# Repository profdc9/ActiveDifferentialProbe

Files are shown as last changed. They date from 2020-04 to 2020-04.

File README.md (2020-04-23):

This is an Active RF Differential Probe based on a cheaply available 2SC3356 Bipolar Transistor by Daniel L. Marks, KW4TI.  Dual gate Mosfets are getting hard to find, so this is what I suggest as an alternative.

The bandwidth is approximately 1 GHz (-3 dB) with 6 dB gain at low frequency.

The PCB design is distributed under the Creative Commons Shared Alike Attribution (CC-BY-SA 4.0) license.

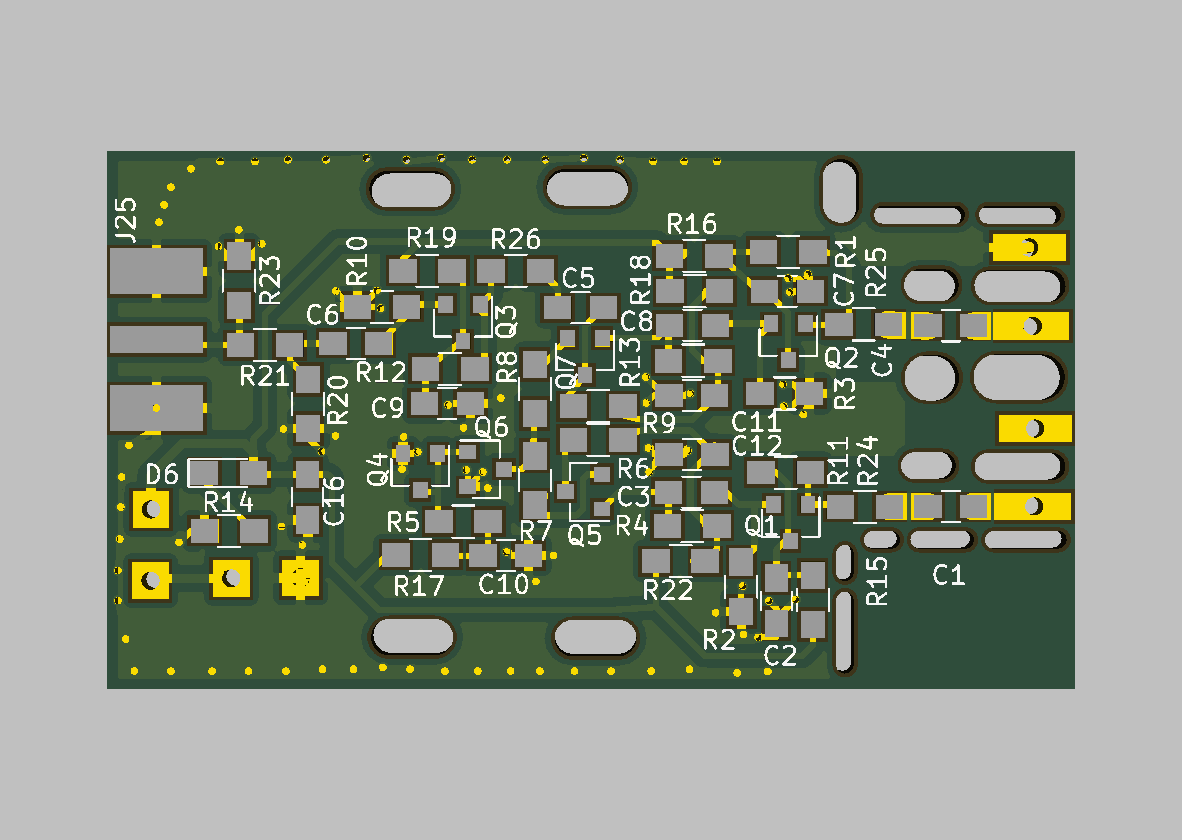
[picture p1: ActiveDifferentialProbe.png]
x


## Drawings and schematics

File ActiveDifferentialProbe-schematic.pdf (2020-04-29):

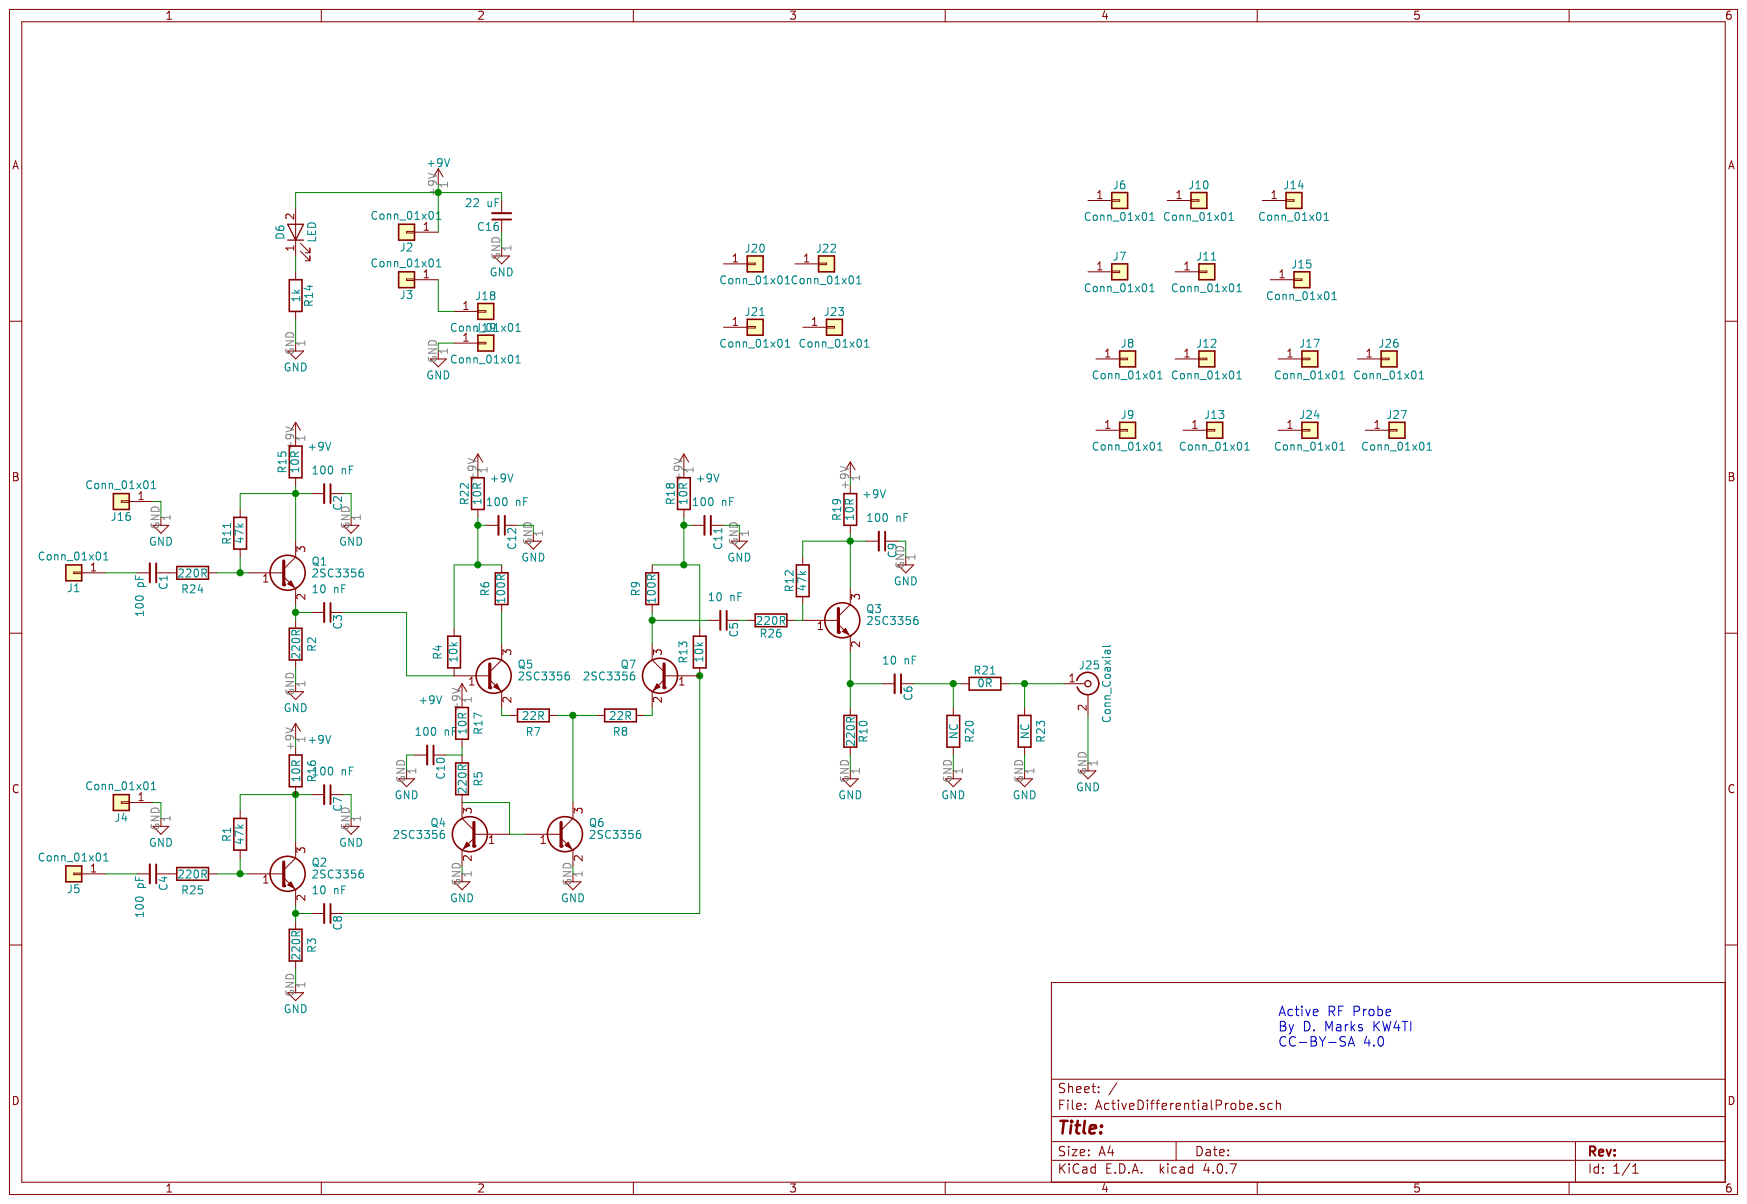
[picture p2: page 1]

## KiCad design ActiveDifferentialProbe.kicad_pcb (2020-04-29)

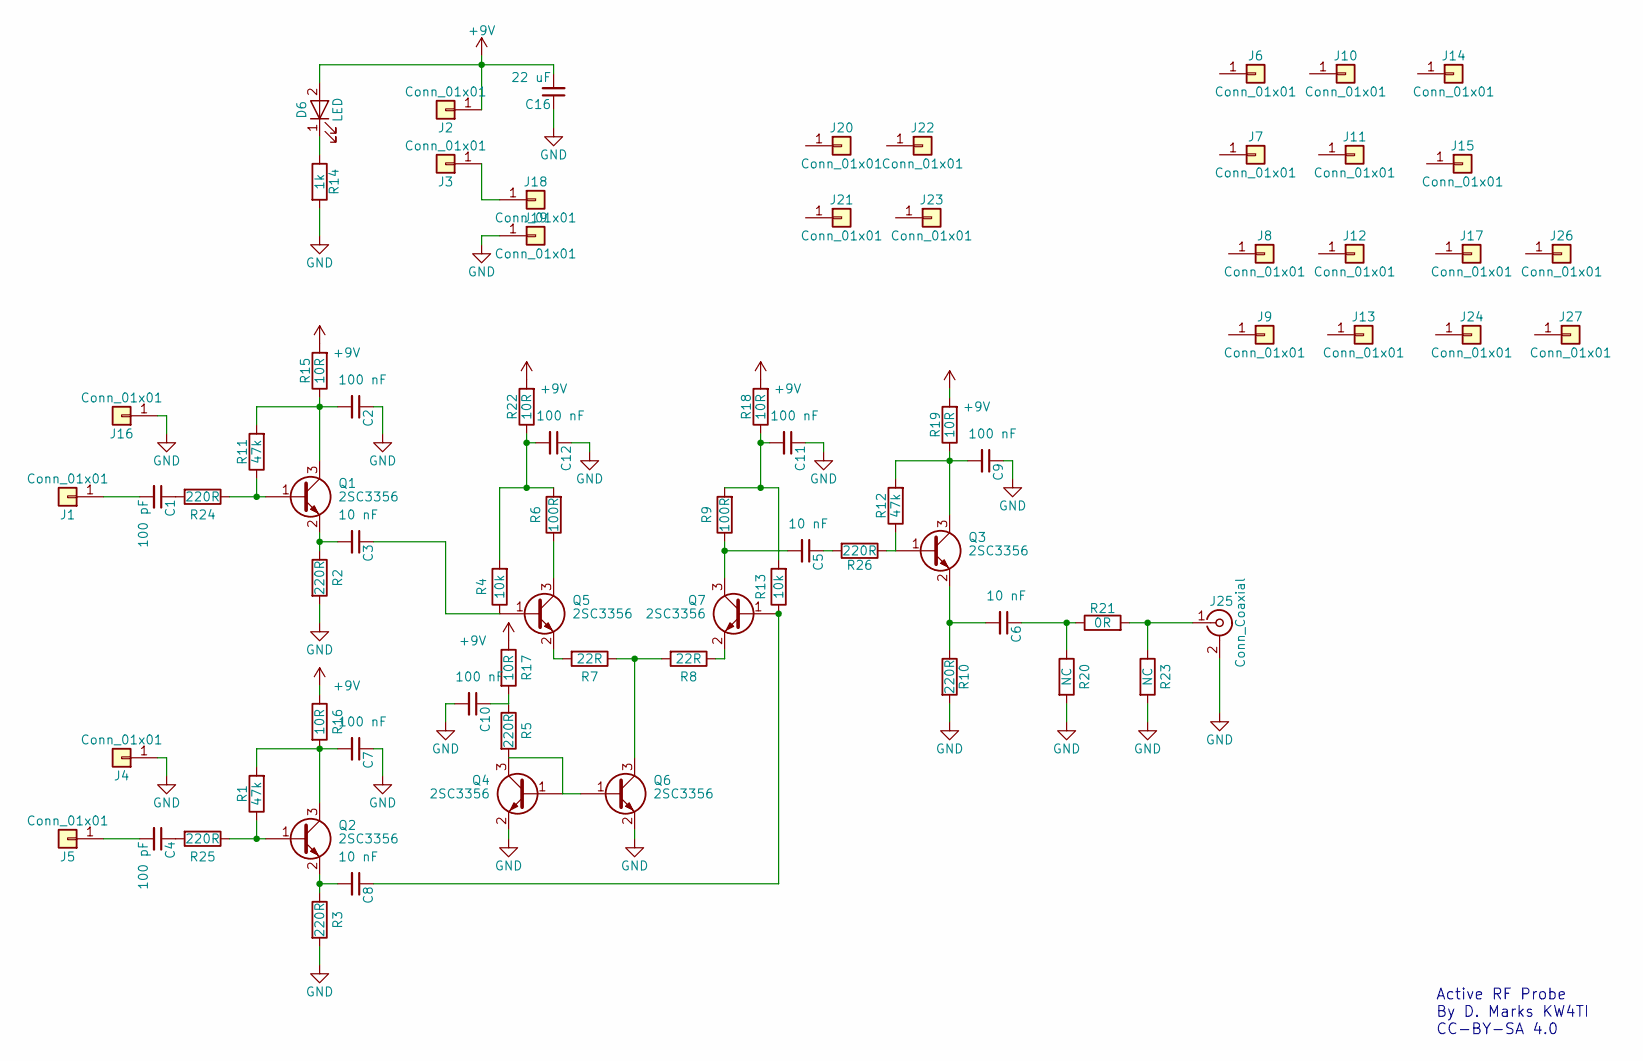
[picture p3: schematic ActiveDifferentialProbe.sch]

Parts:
C1, C4: 100 pF; C_0805_HandSoldering; LCSC C1790
C2, C7, C9, C10, C11, C12: 100 nF; C_0805_HandSoldering; LCSC C49678
C3, C5, C6, C8: 10 nF; C_0805_HandSoldering; LCSC C1710
C16: 22 uF; C_0805_HandSoldering; LCSC C45783
D6: LED; LED_0805_HandSoldering; LCSC C2296
J1, J2, J3, J4, J5, J16, J18, J19: Conn_01x01; PadHole
J6, J7, J8, J9, J10, J11, J12, J13, J14, J15, J17, J20, J21, J22, J23, J24, J26, J27: Conn_01x01; BigSlot
J25: Conn_Coaxial; Amphenol_RF_SMA_132289
Q1, Q2, Q3, Q4, Q5, Q6, Q7: 2SC3356; SOT-23; LCSC C9659
R1, R11, R12: 47k; R_0805_HandSoldering; LCSC C17713
R2, R3, R5, R10, R24, R25, R26: 220R; R_0805_HandSoldering; LCSC C17557
R4, R13: 10k; R_0805_HandSoldering; LCSC C17414
R6, R9: 100R; R_0805_HandSoldering; LCSC C17408
R7, R8: 22R; R_0805_HandSoldering; LCSC C17561
R14: 1k; R_0805_HandSoldering; LCSC C17513
R15, R16, R17, R18, R19, R22: 10R; R_0805_HandSoldering; LCSC C17415
R20, R23: NC; R_0805_HandSoldering
R21: 0R; R_0805_HandSoldering; LCSC C17477

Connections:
+9V: C16.2, D6.2 (A), J2.1, R15.2, R16.1, R17.1, R18.2, R19.2, R22.2
GND: C2.1, C7.1, C9.1, C10.2, C11.1, C12.1, C16.1, J4.1, J16.1, J19.1, J25.2 (Ext), Q4.2 (E), Q6.2 (E), R2.2, R3.2, R10.2, R14.2, R20.2, R23.2
unnamed: C1.1, R24.2
unnamed: C1.2, J1.1
unnamed: C2.2, Q1.3 (C), R11.2, R15.1
unnamed: C3.1, Q5.1 (B), R4.1
unnamed: C3.2, Q1.2 (E), R2.1
unnamed: C4.1, R25.2
unnamed: C4.2, J5.1
unnamed: C5.1, R26.2
unnamed: C5.2, Q7.3 (C), R9.1
unnamed: C6.1, R20.1, R21.1
unnamed: C6.2, Q3.2 (E), R10.1
unnamed: C7.2, Q2.3 (C), R1.2, R16.2
unnamed: C8.1, Q7.1 (B), R13.1
unnamed: C8.2, Q2.2 (E), R3.1
unnamed: C9.2, Q3.3 (C), R12.2, R19.1
unnamed: C10.1, R5.1, R17.2
unnamed: C11.2, R9.2, R13.2, R18.1
unnamed: C12.2, R4.2, R6.2, R22.1
unnamed: D6.1 (K), R14.1
unnamed: J3.1, J18.1
unnamed: J25.1 (In), R21.2, R23.1
unnamed: Q1.1 (B), R11.1, R24.1
unnamed: Q2.1 (B), R1.1, R25.1
unnamed: Q3.1 (B), R12.1, R26.1
unnamed: Q4.1 (B), Q4.3 (C), Q6.1 (B), R5.2
unnamed: Q5.2 (E), R7.2
unnamed: Q5.3 (C), R6.1
unnamed: Q6.3 (C), R7.1, R8.2
unnamed: Q7.2 (E), R8.1

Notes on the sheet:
Active RF Probe By D. Marks KW4TI CC-BY-SA 4.0

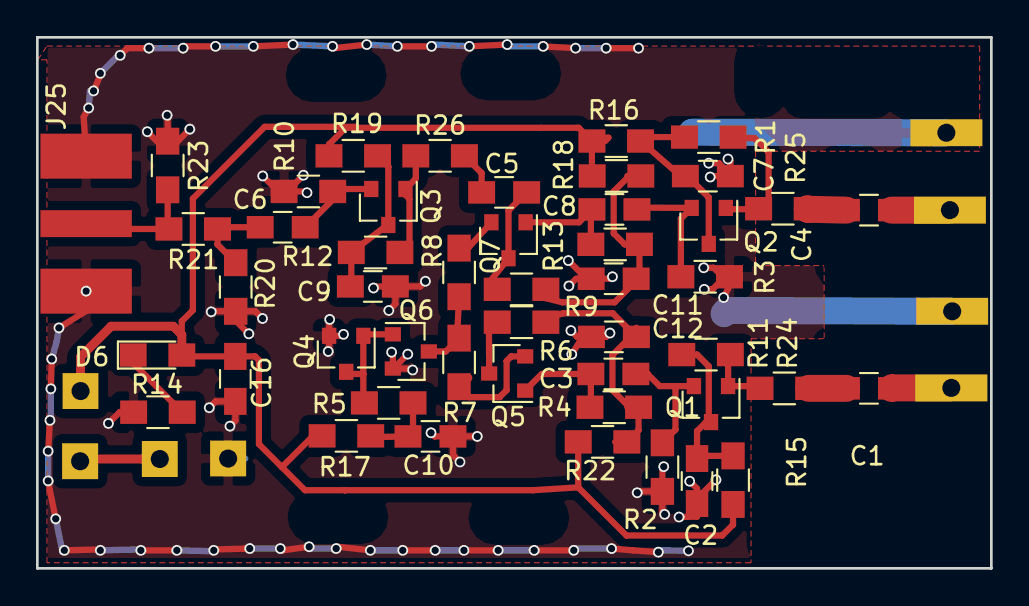
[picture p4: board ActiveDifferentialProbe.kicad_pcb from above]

Board: 2 copper layers, 53.0 x 29.5 mm, 74 parts (0 on the bottom side), 31 nets.

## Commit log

2020-04-22 Added LCSC parts, fixed symbol, added decoupling resistors
    [ActiveDifferentialProbe-B.Cu.gbr, ActiveDifferentialProbe-B.Mask.gbr, ActiveDifferentialProbe-B.SilkS.gbr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]
2020-04-23 Changed to 2SC3356
    [ActiveDifferentialProbe-B.Cu.gbr, ActiveDifferentialProbe-B.Mask.gbr, ActiveDifferentialProbe-B.SilkS.gbr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]
2020-04-29 Added LCSC part numbers, added cutout notched, added series base resistors to emitter followers
    [ActiveDifferentialProbe-B.Cu.gbr, ActiveDifferentialProbe-B.Mask.gbr, ActiveDifferentialProbe-B.SilkS.gbr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]
